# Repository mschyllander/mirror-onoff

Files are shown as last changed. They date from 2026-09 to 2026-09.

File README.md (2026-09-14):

<div align="center">

# MR MATZO / MIRROR CONTROLLER

### Turn on the mirror. Let the timer take care of the rest.

Automatic timer · Current sensing · Local web app · 3D-printed enclosure

[Hardware](docs/hardware.md) · [Measurements](docs/measurements.md) · [Enclosure](hardware/enclosure/) · [Gallery](docs/gallery.md)

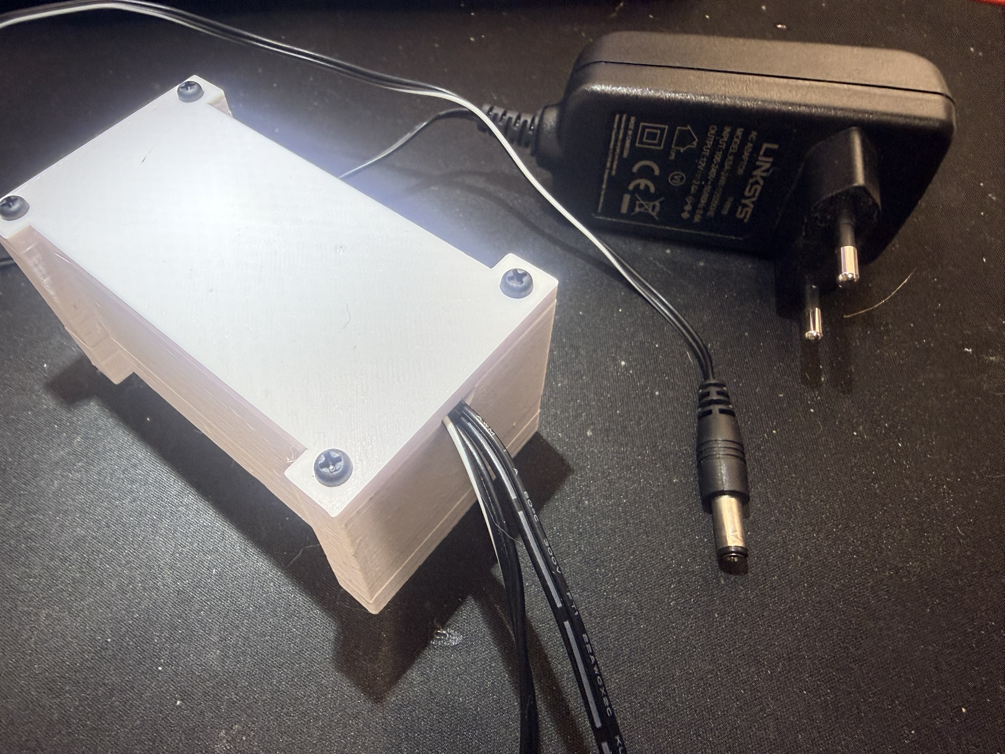
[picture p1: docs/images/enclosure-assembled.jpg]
Assembled mirror controller enclosure


**12 V mirror supply** &nbsp; / &nbsp; **INA219** &nbsp; / &nbsp; **ESP-12E**

</div>

## Why this exists

My wife never turns off her makeup mirror when she's finished. So I did what any reasonable person would do: built a Wi-Fi-enabled controller with current sensing, a web app and a custom 3D-printed enclosure to turn it off for her.

One forgotten light. One perfectly reasonable engineering project. ❤️

## The project

MrMatzo Mirror Controller is an ESP8266 timer app that switches a mirror's 12 V supply through a MOSFET. An INA219 measures current to detect when the mirror light is on and start an automatic timer. When the timer expires, the controller cuts power for three seconds to reset the mirror, then restores the 12 V supply.

The local web app at [mirror.local](http://mirror.local) displays current, voltage, power and remaining time. It also lets you set the timer duration and control the supply manually.

**Firmware 1.4.1 includes automatic shutdown recovery and password-protected browser OTA, with separate web and direct Wi-Fi passwords.** It has been compiled for NodeMCU 1.0 (ESP-12E) and checked with automated control-logic and upload-handler tests. Physical verification on the mirror is still required. The web interface and status messages are in Swedish. See [installation and OTA](firmware/README.md).

## How the timer works

1. The INA219 is read approximately every 100 ms. A moving average of ten samples smooths the current reading.
2. At least 31 mA for 700 ms confirms that the light is on and starts the timer when automatic mode is enabled and rearming is allowed.
3. The timer defaults to **10 minutes** and can be set to **1–1440 minutes**. The duration is saved in LittleFS.
4. When time runs out, 12 V is disconnected for **3 seconds**. Power is restored, followed by a **5-second** detection lockout.
5. A reading of at most 26 mA for 1000 ms confirms that the light is off. If it comes back on, the controller retries with **10-second**, then **30-second** interruptions.
6. If all three attempts fail, the controller **leaves 12 V off** and displays a fault. The fault persists across restart when LittleFS is available. Use the manual power-on button to acknowledge it. An unknown state after restoration also triggers bounded recovery.

Turning off the light before the timer expires stops the countdown. Between 26 and 31 mA, an already known light state is retained.

```mermaid
flowchart LR
    A[Light confirmed on] --> B[Timer counts down]
    B --> C[Cut 12 V for 3 s]
    C --> D[Restore 12 V]
    D --> E[Wait 5 s]
    E --> F{Light confirmed off?}
    F -->|Yes| A
    F -->|No| G[Retry with 10 s, then 30 s off]
    G --> H{Still not off?}
    H -->|Yes| I[Keep 12 V off until acknowledged]
    H -->|No| A
```

[Firmware and operation →](firmware/README.md)

## From prototype to enclosure

<table>
<tr>
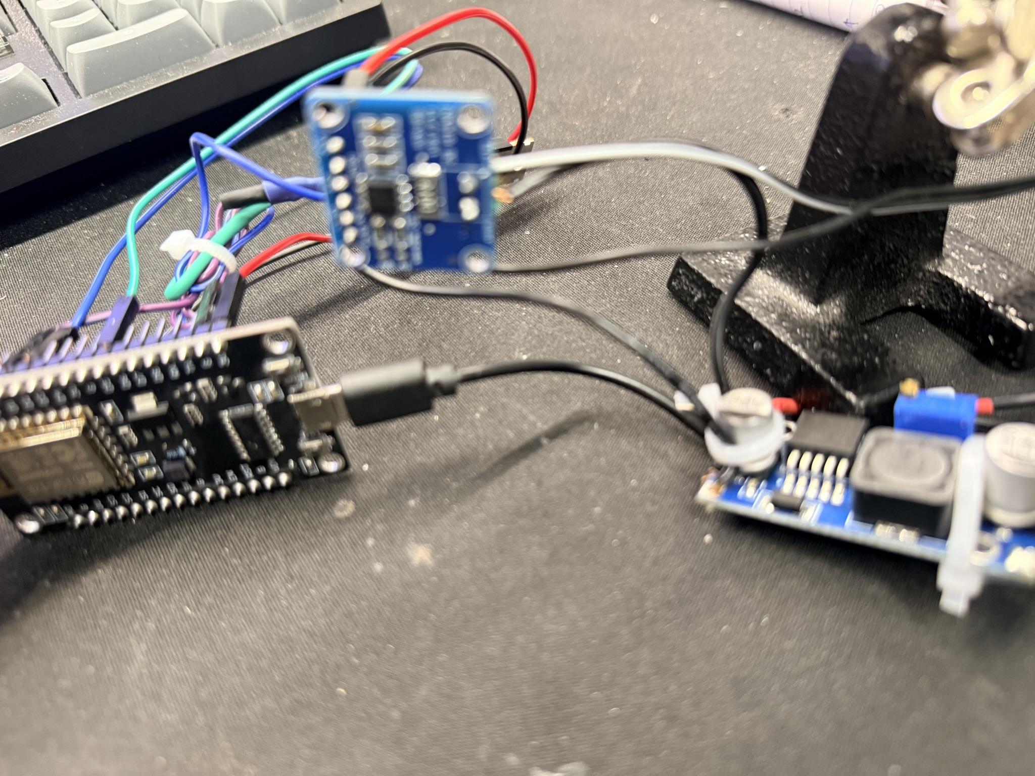
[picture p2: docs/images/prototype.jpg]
Electronics prototype on the workbench
<td width="50%"></td>
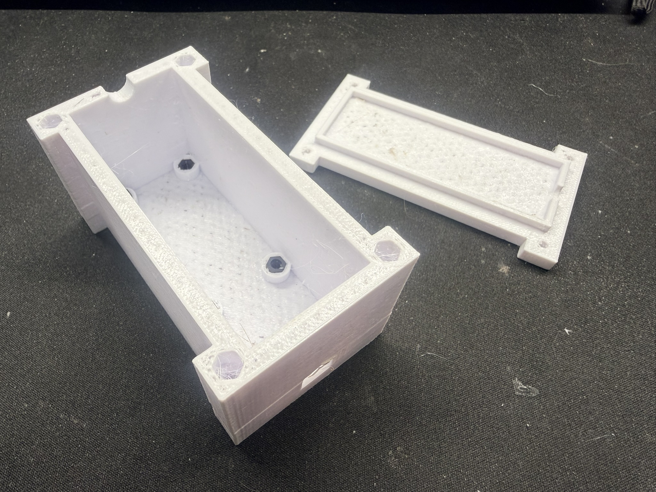
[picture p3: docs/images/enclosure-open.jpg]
3D-printed enclosure with separate lid
<td width="50%"></td>
</tr>
<tr><td><b>The electronics</b><br>Controller, current sensor and voltage converter.</td><td><b>The enclosure</b><br>Printed case with lid, screw mounts and cable openings.</td></tr>
</table>

## Current measurements

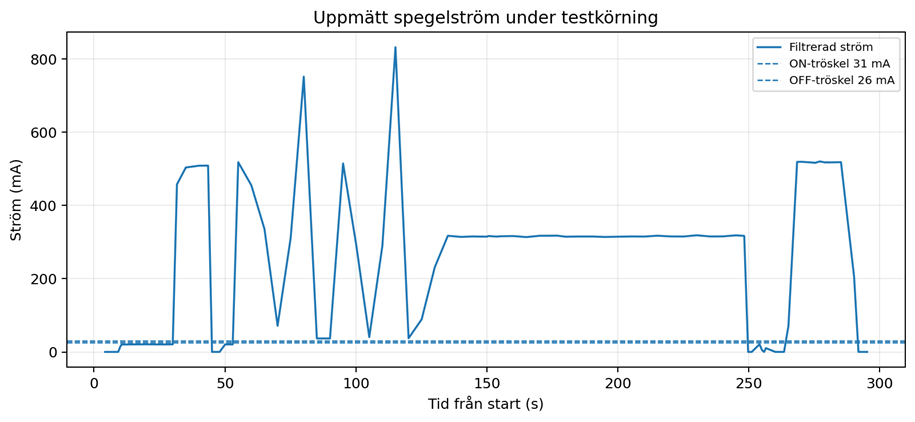
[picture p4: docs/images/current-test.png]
Measured mirror current during a test run


| Parameter | Value shown in the source material |
| :--- | :--- |
| ON threshold | 31 mA |
| OFF threshold | 26 mA |
| Threshold gap | 5 mA |
| Test duration | Approximately 295 seconds |

The plot shows steady current levels and brief peaks. The firmware uses hysteresis and confirmation periods to distinguish between on and off. The original plot has Swedish labels; an English label guide is included in the [measurement notes →](docs/measurements.md)

## Explore the repository

| Content | Location |
| :--- | :--- |
| Components and outstanding wiring details | [Hardware](docs/hardware.md) |
| Test plot and interpretation | [Measurements](docs/measurements.md) |
| All project photos | [Gallery](docs/gallery.md) |
| Enclosure model | [Box_mirror_onoff.3mf](hardware/enclosure/Box_mirror_onoff.3mf) |
| Firmware 1.3 and operation | [Firmware](firmware/README.md) |
| Remaining documentation | [Next steps](docs/next-steps.md) |

## Using the files

Open the 3MF file in compatible CAD or slicing software to inspect the enclosure. The model uses millimeters and contains two model objects. Check print settings and fit before printing; see the [enclosure documentation](hardware/enclosure/README.md).

The Arduino sketch, verified build configuration and OTA instructions are in [firmware](firmware/README.md). Firmware 1.3 needs one USB installation before wireless updates are available. A fully verified physical wiring diagram remains to be documented.

## License

Released under the [MIT License](LICENSE). Copyright © 2026 Mats Schyllander.

You are welcome to use and modify your own copy. Changes to this repository are
managed by the maintainer; see [Contributing](CONTRIBUTING.md).

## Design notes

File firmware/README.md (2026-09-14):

# Firmware · MrMatzo Mirror Controller 1.4.1

[Arduino sketch](esp_12V_mirror_timer/esp_12V_mirror_timer.ino) · [Release notes](../CHANGELOG.md)

## Install once by USB, then update over Wi-Fi

Version 1.3 has no OTA receiver. It must be replaced over USB once. Version 1.4.0 adds a browser upload page at `/update`; future updates can use that page.

1. Copy `DeviceConfig.example.h` to `DeviceConfig.h` in the sketch folder.
2. Set `MIRROR_ADMIN_PASSWORD` for the admin/update pages and `MIRROR_AP_PASSWORD` for direct Wi-Fi (8–63 ASCII characters). These are independent as of 1.4.1. The private header is ignored by Git; keep it for future builds.
3. Open `esp_12V_mirror_timer.ino` in Arduino IDE. Select **NodeMCU 1.0 (ESP-12E Module)** for the photographed board, and verify the actual board and flash capacity before uploading.
4. Compile and upload over USB using the settings below. Preserve the filesystem and Wi-Fi settings; do not erase all flash.
5. Open [mirror.local](http://mirror.local) on the same network, or use the device IP address. For a direct connection, join **Mirror-Setup** using your configured Wi-Fi password and open [192.168.4.1](http://192.168.4.1).
6. Select **UPPDATERA**, sign in as `admin` with your configured admin password, select the firmware `.bin` and install it. Keep the controller powered until it restarts, then check the firmware version at `/status`.

The spelling is `mirror.local`. Hostname resolution depends on the client/network; the IP address is the fallback. Direct Wi-Fi does not require a router or internet access. A phone may report that Mirror-Setup has no internet; stay connected to use the controller.

### Build verified for 1.4.0

| Component | Version / setting |
| :--- | :--- |
| ESP8266 Arduino core | 3.1.2 |
| Board FQBN | `esp8266:esp8266:nodemcuv2` |
| Flash layout | Board default: 4 MB flash, 2 MB filesystem |
| Adafruit INA219 | 1.2.3 |
| Adafruit BusIO | 1.17.4 |
| Serial monitor | 921600 baud |

The remaining libraries are supplied by the ESP8266 core: WiFi, WebServer, mDNS, Wire, LittleFS and Updater. WiFiManager is no longer required. The web app is embedded in the sketch.

```sh
arduino-cli compile --fqbn esp8266:esp8266:nodemcuv2 firmware/esp_12V_mirror_timer
```

Use the same flash layout as the installed firmware to retain logs/settings. The project device was read back on 2026-09-14: 4 MB flash with LittleFS from `0x200000` to `0x3FA000`, matching this profile. A binary built with your private header contains the password and should not be published as a generic release artifact.

## Automatic shutdown recovery

The previous firmware could cut power successfully, restore it to an illuminated mirror and then wait forever for OFF with no active timer. Version 1.4.0 retains the OFF confirmation requirement but adds a bounded recovery sequence:

| Attempt | Power off | After restoration |
| :--- | :--- | :--- |
| 1 | 3 seconds | Wait 5 seconds, then confirm light state |
| 2, if needed | 10 seconds | Wait 5 seconds, then confirm light state |
| 3, if needed | 30 seconds | Wait 5 seconds, then confirm light state |

A confirmed ON starts the next attempt immediately. If the state remains unknown for 15 seconds after restoration, the next attempt starts as well. After the third failure, 12 V remains off with **AVSTÄNGD EFTER SLÄCKFEL**. Manual power-on acknowledges the fault. If LittleFS is working, `/shutdown_fault.txt` preserves the fault across a controller restart; a filesystem failure prevents that persistence.

Confirmation of OFF clears the recovery sequence and allows the next normal timer. Manual OFF cancels any pending power restoration. Manual power cycling remains a single three-second interruption and clears the automatic rearm condition.

## Detection and timer settings

| Parameter | Value |
| :--- | :--- |
| Timer duration | 1–1440 minutes; default 10 minutes |
| Sensor interval | 100 ms, subject to main-loop scheduling |
| Filter | Moving average of 10 samples; negative raw readings clamped to 0 |
| Light on | Filtered current ≥ 31 mA for 700 ms |
| Light off | Filtered current ≤ 26 mA for 1000 ms |
| Between thresholds | Known state retained; unknown state remains unknown |
| Sensor calibration | `setCalibration_32V_2A()` |

Turning off the light stops an active timer. Changing the duration during a countdown starts a fresh countdown. Duration persists across restart; automatic mode and countdown progress do not. Automatic mode starts enabled. A latched shutdown fault keeps the supply off at boot; otherwise supply power is enabled.

If the sensor is missing at startup, the UI reports a sensor error and normal current detection is unavailable. This firmware does not provide an independent hardware cutoff or complete sensor-failure protection.

## Wi-Fi and update behavior

- The password-protected **Mirror-Setup** access point remains available alongside the existing home Wi-Fi connection.
- `/wifi` lets an authenticated administrator save new router credentials. Existing credentials from 1.3 are reused. Timer processing no longer waits for router connection or a blocking setup portal.
- OTA and Wi-Fi configuration use HTTP Digest authentication and a per-boot form token. Firmware uploads accept `.bin` files and write only the firmware area, not a filesystem image.
- An authorized firmware upload turns the mirror supply off and cancels pending automatic restoration. Failed or aborted uploads leave it off. A successful upload restarts the controller.
- Keep using the same private password header when building updates, unless intentionally changing a password. No device password is committed to this repository or returned by `/status`.
- Ordinary mirror controls remain unauthenticated on the local network, as in 1.3. HTTP is not encrypted; do not expose the controller through internet port forwarding. OTA images are not cryptographically signed.

## Logs and endpoints

Measurements are logged every ten seconds and at events. LittleFS retains `/mirror_log.csv` and one rotated `/mirror_log_old.csv`; rotation occurs when the current file reaches 200 KiB. The previous file is now available for download too. Rotation is finite retention, not a permanent archive.

CSV fields remain `session,uptime_ms,raw_mA,filtered_mA,bus_V,load_V,power_mW,state,event`. Time is uptime in milliseconds. `load_V` follows the original code's calculation of bus voltage plus shunt voltage.

| Path | Function |
| :--- | :--- |
| `/`, `/status` | Web app and JSON status |
| `/settime?minutes=10`, `/auto/toggle` | Duration and automatic mode |
| `/power/on`, `/power/off`, `/reset` | Manual supply control and power cycle |
| `/log`, `/log/download` | Current log |
| `/log/old/download` | Previous rotated log |
| `/log/clear` | Clear both log files |
| `/update` | Authenticated firmware upload |
| `/wifi` | Authenticated Wi-Fi configuration |
| `/wifi-reset` | Redirect to configuration; no longer erases credentials |

JSON status adds `shutdownFault`, `shutdownAttempt`, `otaInProgress` and `apIP`. New log events include `SHUTDOWN_RETRY_2`, `SHUTDOWN_RETRY_3`, `SHUTDOWN_CONFIRMED_OFF`, `SHUTDOWN_FAILED_LATCHED_OFF`, `OTA_STARTED`, `OTA_SUCCESS`, `OTA_FAILED`, `OTA_ABORTED` and `OTA_TIMEOUT`.

## Validation

```sh
python tests/test_controller.py
python tests/test_ota.py
```

These tests compile the actual sketch functions with C++ hardware stubs. They cover the observed 524 mA recovery failure, normal rearming, bounded retries, manual cancellation, unknown state, a missing sensor during recovery, threshold timing, millis rollover and filtering. Upload tests cover authentication, form tokens, missing/wrong files, flash errors, aborts and successful retry.

The firmware compiles for the profile above. On 2026-09-14, version 1.4.0 was installed over USB on the project device after a full flash backup. An authenticated OTA transfer of the same firmware completed successfully, followed by a verified reboot and `OTA_SUCCESS` in the log. The timer setting and filesystem were retained. Both the local hostname and LAN IP responded, the INA219 was detected, and unauthenticated access to `/update` returned HTTP 401. A separate direct Wi-Fi connection and physical mirror shutdown/retry test remain outstanding.

[Back to the project](../README.md)

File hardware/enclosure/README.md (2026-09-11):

# Enclosure

Printed enclosure and lid

[Download the 3MF model](Box_mirror_onoff.3mf)

The original file is included unchanged. The 3MF archive is readable and contains a model with two objects, millimeter units and an embedded preview. Printability and fit have not been verified.

## Embedded model preview

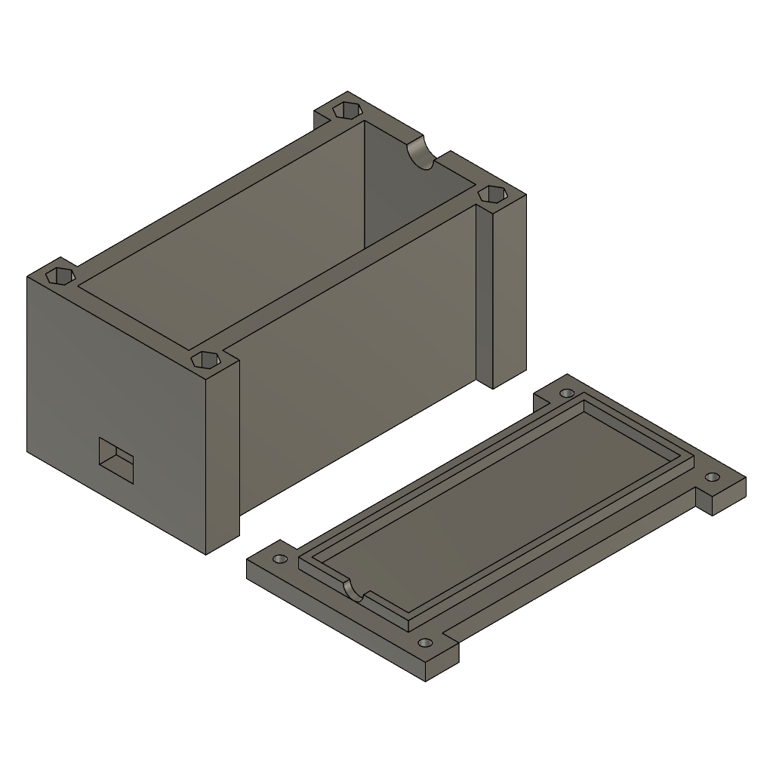
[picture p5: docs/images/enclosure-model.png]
Model preview embedded in the 3MF file


## Print details to document

| Detail | Status |
| :--- | :--- |
| Material | Not specified |
| Nozzle and layer height | Not specified |
| Walls and infill | Not specified |
| Orientation and supports | Not specified |
| Screws and nuts | Sizes not specified |
| Fit around the electronics | Not verified in this repository |

[Back to the project](../../README.md)

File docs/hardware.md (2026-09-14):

# Hardware

This overview is based on the project photos and firmware (GPIO assignments unchanged in 1.4.0). It is a component inventory, not a verified wiring diagram.

| Part | Identification from the photos | Still to document |
| :--- | :--- | :--- |
| Controller | ESP8266, module marked ESP-12E; board with D0–D8 and micro-USB | Exact board variant and power connection |
| Current sensor | INA219 DC Current Sensor, shunt marked R100 | Physical I²C address and wiring; code uses the default constructor and 32 V / 2 A calibration |
| Transistor | Separate component marked IRLB8721 | Confirm its installation and connections in the MOSFET switching circuit |
| DC/DC module | Adjustable module with a trimmer potentiometer | Exact model and configured input/output voltages |
| White power adapter | Royal BI24G-120200-AdV, output 12.0 V DC / 2.0 A / 24.0 W | Which adapter is used in the final build |
| Black power adapter | Linksys adapter visible beside the enclosure | Ratings and role in the project |
| Enclosure | Printed case with a separate screw-fastened lid | Material, screw sizes and mounting dimensions |

## GPIO assignments in the source

| Signal | Board pin | GPIO | Connection described in the source |
| :--- | :--- | :--- | :--- |
| MOSFET control | D1 | 5 | Gate through 100 Ω; gate to GND through 10 kΩ, according to the code comment |
| INA219 SDA | D2 | 4 | I²C data |
| INA219 SCL | D5 | 14 | I²C clock |

`setMirrorPower()` drives D1 HIGH for power on and LOW for power off. These pins are used in the implementation; the resistor values come from the introductory code comment. The physical wiring still needs to be checked against the build.

## Wiring

The photos do not establish the complete wiring. A reproducible build needs:

- The supply path through the mirror, sensor and controller.
- INA219 connections: VCC, GND, SDA, SCL, VIN+ and VIN−.
- IRLB8721 connections and any supporting components.
- The DC/DC module's configured output voltage and connection to the controller.
- Connector polarity and confirmation of the GPIO assignments above.

Do not infer connections solely from wire colors in the photos.

[Component photos](gallery.md) · [Back to the project](../README.md)

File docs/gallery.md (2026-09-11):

# Photo gallery

Original project images, copied without image processing.

## Assembled enclosure

Assembled enclosure

The case with its lid screwed on. A black Linksys power adapter sits beside it.

## Case and lid

Case and lid

The enclosure interior, mounts and cable openings.

## Prototype

Prototype

The electronics on the workbench during development.

## Controller board

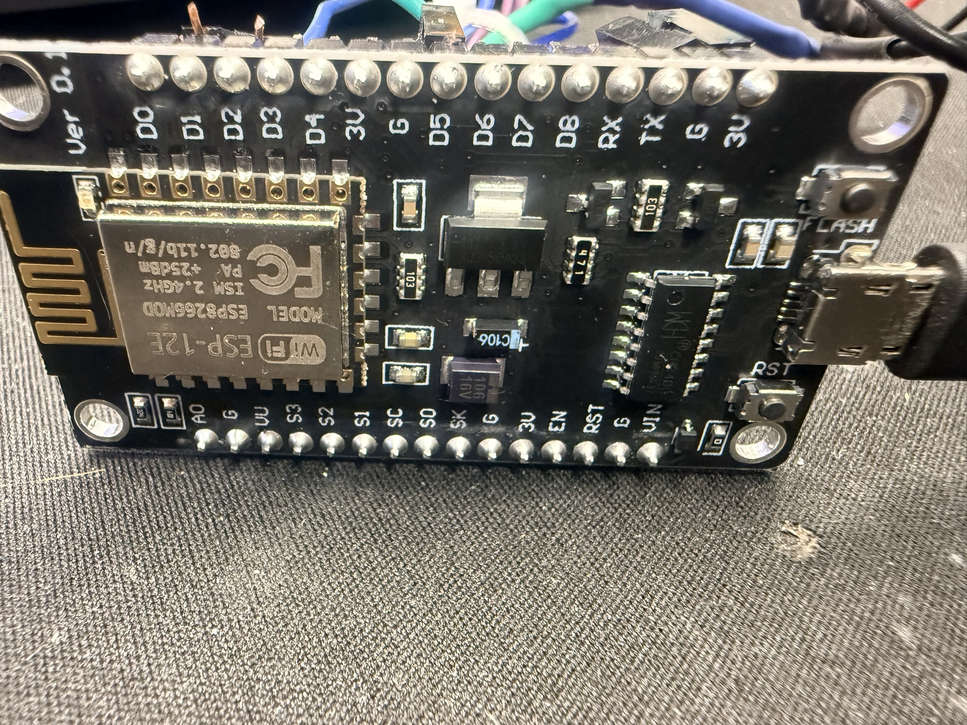
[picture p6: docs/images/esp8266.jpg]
Controller board


ESP8266 board with an ESP-12E module.

## Current sensor

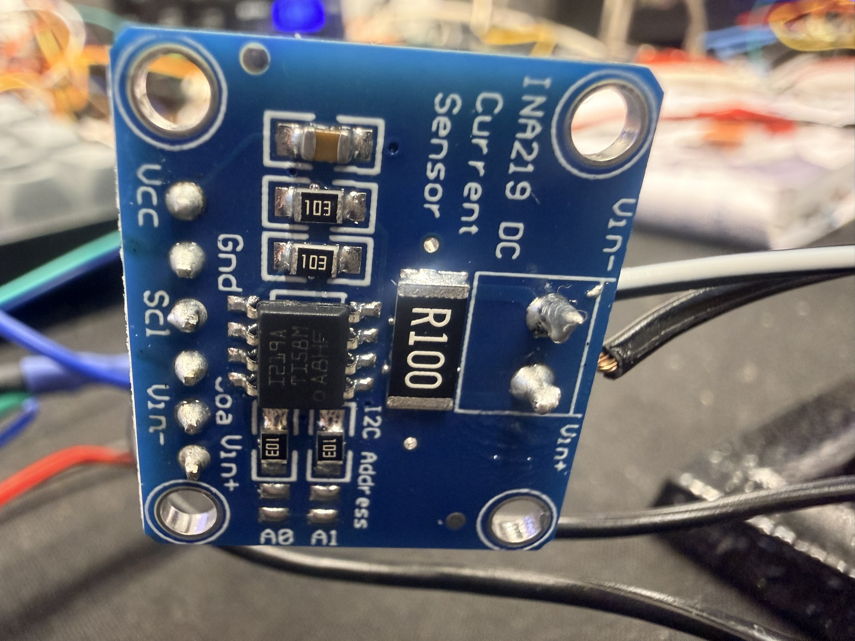
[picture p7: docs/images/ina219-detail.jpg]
Current sensor


A close-up of the INA219 module.

## Current sensor, alternate view

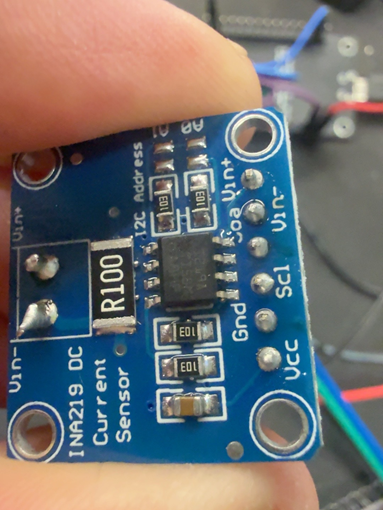
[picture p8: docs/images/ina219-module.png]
Current sensor, alternate view


Module markings and connections.

## DC/DC module

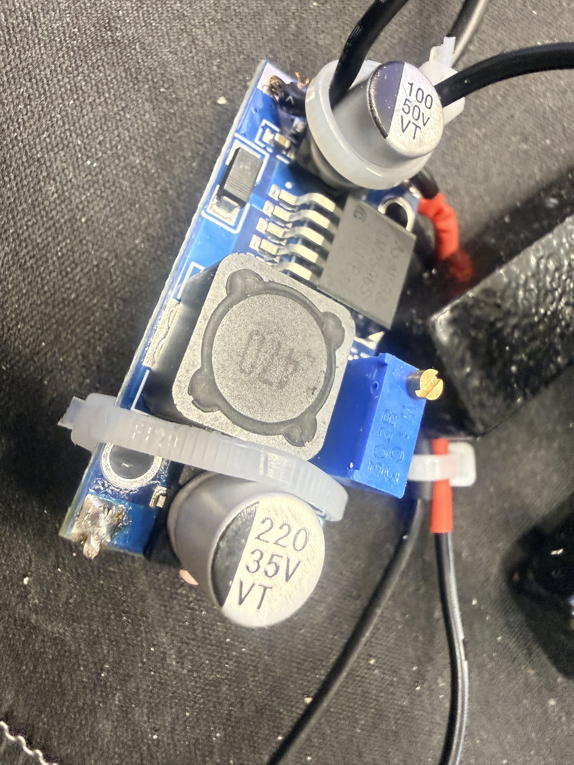
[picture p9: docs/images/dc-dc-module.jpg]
DC/DC module


Adjustable voltage converter.

## IRLB8721

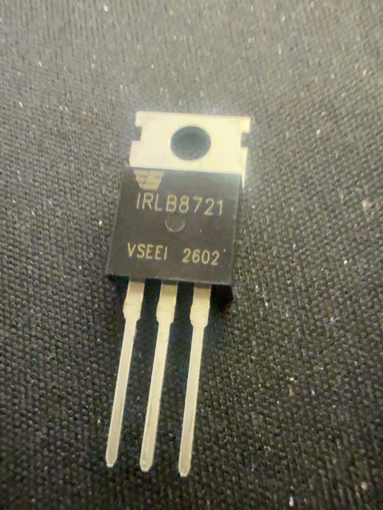
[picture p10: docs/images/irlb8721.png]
IRLB8721


The separate component, photographed before its installation was documented.

## White power adapter

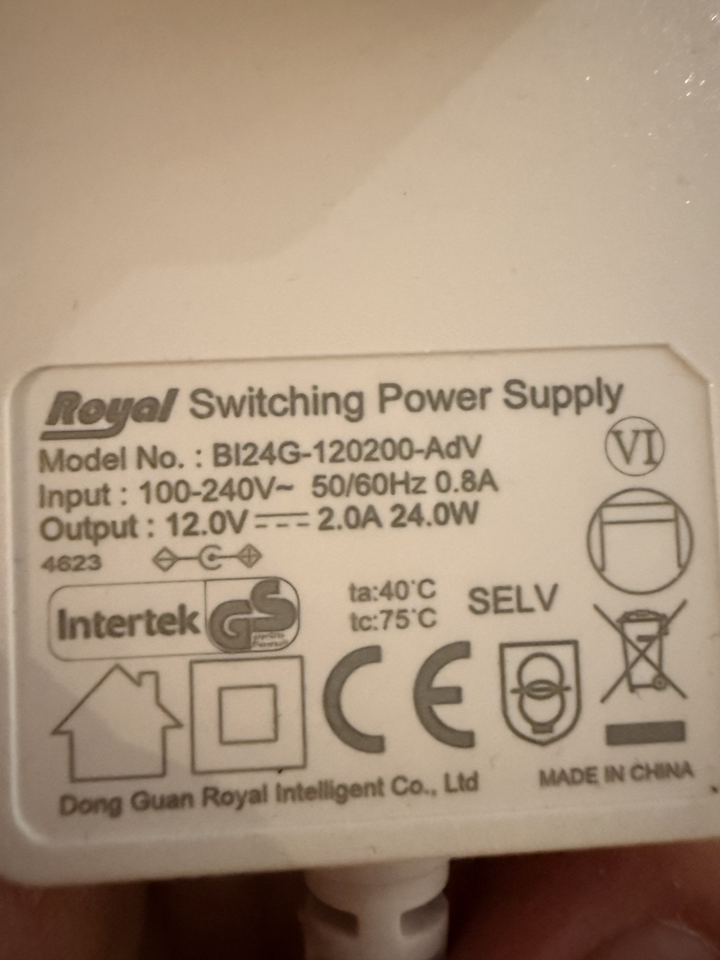
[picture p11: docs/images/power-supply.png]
White power adapter


Output rating: 12.0 V DC, 2.0 A and 24.0 W.

## Test run

Test run

Filtered current with marked thresholds. See the [measurement notes](measurements.md) for an English guide to the original Swedish labels.

[Back to the project](../README.md)

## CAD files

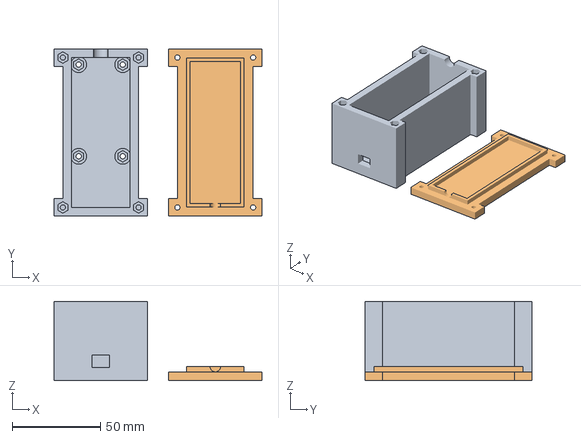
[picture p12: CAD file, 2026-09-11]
hardware/enclosure/Box_mirror_onoff.3mf
118.0 x 95.0 x 45.0 mm
Lada
Lock

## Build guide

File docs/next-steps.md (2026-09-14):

# Next steps

- [x] Collect project photos with descriptive filenames.
- [x] Include the original enclosure model.
- [x] Present the hardware and test plot.
- [x] Describe the mirror's behavior and the controller's purpose.
- [x] Include firmware 1.3 and document its operation.
- [x] Write the repository documentation in English.
- [x] Compile firmware 1.4.0 with documented NodeMCU / ESP8266 core / library versions.
- [x] Add and test bounded shutdown recovery and browser OTA.
- [x] Verify actual board flash layout, back up flash and install 1.4.0 over USB.
- [x] Verify authenticated OTA transfer, reboot, log event and preserved settings on the device.
- [ ] Verify shutdown recovery with the mirror connected and test a separate direct Wi-Fi connection.
- [ ] Document and verify the wiring diagram against the hardware; GPIO assignments are available from the source.
- [ ] Confirm which power adapter is used.
- [ ] Document print settings and mounting hardware.
- [ ] Add raw data and instructions for repeating the measurement.
- [x] Select the MIT license.
- [x] Publish on GitHub as `mschyllander/mirror-onoff` with public visibility.

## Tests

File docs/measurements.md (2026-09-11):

# Current measurements

Test run showing filtered current and ON/OFF thresholds

## Source material

The original plot is in Swedish. Its title translates to **Measured mirror current during a test run**. The horizontal axis shows seconds since startup; the vertical axis shows current in mA. The curve is labeled *Filtered current*.

| Original label | English |
| :--- | :--- |
| Tid från start (s) | Time since startup (s) |
| Ström (mA) | Current (mA) |
| Filtrerad ström | Filtered current |
| ON-tröskel 31 mA | ON threshold 31 mA |
| OFF-tröskel 26 mA | OFF threshold 26 mA |

No raw data file was supplied. Firmware 1.3 uses a moving average of ten current samples with a 100 ms read interval. It has not been established whether this exact version produced the plot.

## Reading the plot

| Observation | Approximate value |
| :--- | :--- |
| ON threshold stated in the legend | 31 mA |
| OFF threshold stated in the legend | 26 mA |
| Longer plateau, roughly 135–248 s | 315 mA |
| Higher plateaus | 500–520 mA |
| Highest visible peak | 830 mA |

Plateaus, times and the peak value are visual estimates from the image. Threshold values are explicitly stated in the legend.

## Firmware 1.3 logic

The thresholds are 5 mA apart. The code confirms ON when filtered current stays at or above 31 mA for 700 ms, and OFF at or below 26 mA for 1000 ms. Between thresholds, a known state is retained. Confirmed ON starts the timer when automatic mode is enabled and the rearming condition allows it.

The introductory code comment records approximately 20–21.5 mA with the mirror light off and 36–40 mA at its lowest on level. These are the project's recorded measurements, not new measurements made for this repository.

Reproducing the plot requires raw data, notes about events during the run and confirmation of the firmware version used.

[Firmware and complete timer behavior](../firmware/README.md) · [Back to the project](../README.md)

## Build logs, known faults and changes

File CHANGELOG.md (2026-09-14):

# Changelog

## 1.4.1 — 2026-09-14

- Separate the web admin password from the direct Wi-Fi password, allowing a shorter web password without changing the access point.
- Keep device-specific credentials in the private, gitignored configuration.

## 1.4.0 — 2026-09-14

- Fix the automatic shutdown deadlock when the mirror returns illuminated after a power cycle.
- Retry with 3, 10 and 30 second interruptions, then latch the supply off if shutdown cannot be confirmed.
- Preserve the shutdown fault across reboot in LittleFS; manual power-on acknowledges it.
- Add password-protected browser firmware updates at `/update` and a button in the existing Swedish UI.
- Add password-protected direct Wi-Fi access and `/wifi` configuration without blocking timer processing.
- Make the previous rotated log downloadable.
- Add regression tests for controller behavior and OTA upload handlers.

## 1.3

Original imported firmware: current-triggered timer, Swedish web interface, LittleFS logs and settings, and a single three-second power cycle. No OTA support.

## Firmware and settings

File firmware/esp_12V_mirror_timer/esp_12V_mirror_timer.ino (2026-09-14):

/*
   ============================================================
                 MR MATZO MIRROR CONTROLLER
                        Version 1.4.1
   ============================================================

   ESP8266 + INA219 + MOSFET + LittleFS + mDNS

   Web interface:
      http://mirror.local

   D1 / GPIO5  -> 100R -> MOSFET Gate
   Gate        -> 10k -> GND

   D2 / GPIO4  -> INA219 SDA
   D5 / GPIO14 -> INA219 SCL

   Current measurements from real mirror:

      OFF:       ~20.0 - 21.5 mA
      Lowest ON: ~36.0 - 40 mA
      High ON:   hundreds of mA

   Detection:

      OFF <= 26 mA
      ON  >= 31 mA

   Dead-band between 26 and 31 mA prevents chatter.
*/


// ============================================================
// LIBRARIES
// ============================================================

#include <ESP8266WiFi.h>
#include <ESP8266WebServer.h>
#include <ESP8266mDNS.h>
#include <Updater.h>
#include "ShutdownRecovery.h"
#include "DeviceConfig.h"
#include <Wire.h>
#include <Adafruit_INA219.h>
#include <LittleFS.h>


// ============================================================
// VERSION / NETWORK
// ============================================================

const char* FW_VERSION = "MrMatzo Mirror Controller 1.4.1";

const char* MDNS_HOSTNAME = "mirror";


// ============================================================
// HARDWARE
// ============================================================

const uint8_t MOSFET_PIN  = D1;
const uint8_t I2C_SDA_PIN = D2;
const uint8_t I2C_SCL_PIN = D5;

ESP8266WebServer server(80);
Adafruit_INA219 ina219;
ShutdownRecovery recovery;
bool otaInProgress = false;
bool otaSucceeded = false;
bool otaFailed = false;
bool otaAuthorized = false;
unsigned long otaLastActivity = 0;
bool fsOK = false;
bool mdnsStarted = false;
bool stationWasConnected = false;
String adminNonce;
const char* FAULT_FILE = "/shutdown_fault.txt";
const char* ADMIN_PASSWORD = MIRROR_ADMIN_PASSWORD;
static_assert(sizeof(MIRROR_ADMIN_PASSWORD) > 1, "Set an admin password");
static_assert(sizeof(MIRROR_AP_PASSWORD) >= 9 && sizeof(MIRROR_AP_PASSWORD) <= 64,
              "Choose an 8-63 character Wi-Fi password");


// ============================================================
// FILE SYSTEM
// ============================================================

const char* LOG_FILE      = "/mirror_log.csv";
const char* OLD_LOG_FILE  = "/mirror_log_old.csv";
const char* SETTINGS_FILE = "/settings.txt";
const char* SESSION_FILE  = "/session.txt";

const size_t MAX_LOG_SIZE = 200UL * 1024UL;


// ============================================================
// TIMER SETTINGS
// ============================================================

unsigned long timerIntervalMs =
  10UL * 60UL * 1000UL;

const unsigned long POWER_OFF_TIME_MS =
  3000UL;

const unsigned long SENSOR_LOCKOUT_MS =
  5000UL;


// ============================================================
// CURRENT DETECTION
// ============================================================

const float CURRENT_ON_THRESHOLD_MA =
  31.0;

const float CURRENT_OFF_THRESHOLD_MA =
  26.0;

const unsigned long ON_CONFIRM_MS =
  700UL;

const unsigned long OFF_CONFIRM_MS =
  1000UL;


// ============================================================
// SENSOR
// ============================================================

const unsigned long SENSOR_INTERVAL_MS =
  100UL;

const unsigned long LOG_INTERVAL_MS =
  10000UL;

unsigned long lastSensorRead = 0;
unsigned long lastLogWrite   = 0;

float rawCurrent_mA      = 0.0;
float filteredCurrent_mA = 0.0;

float busVoltage_V       = 0.0;
float loadVoltage_V      = 0.0;
float shuntVoltage_mV    = 0.0;
float power_mW           = 0.0;


// ============================================================
// CURRENT FILTER
// ============================================================

const uint8_t FILTER_SIZE = 10;

float currentBuffer[FILTER_SIZE];

uint8_t filterIndex = 0;
uint8_t filterCount = 0;


// ============================================================
// SYSTEM STATE
// ============================================================

bool inaOK       = false;
bool powerOn     = true;
bool autoEnabled = true;

bool timerActive     = false;
bool resetInProgress = false;
bool sensorLockout   = true;

bool mirrorStateValid = false;
bool mirrorIsOn       = false;

bool requireOffBeforeRearm = false;

bool onCandidate  = false;
bool offCandidate = false;

unsigned long onCandidateStarted  = 0;
unsigned long offCandidateStarted = 0;

unsigned long timerStarted   = 0;
unsigned long resetStarted   = 0;
unsigned long lockoutStarted = 0;

uint32_t sessionNumber = 0;


// ============================================================
// JSON ESCAPE
// ============================================================

String jsonEscape(String s)
{
  s.replace("\\", "\\\\");
  s.replace("\"", "\\\"");
  s.replace("\r", "");
  s.replace("\n", "\\n");

  return s;
}


// ============================================================
// USER-FACING STATE
// ============================================================

String getStateText()
{
  if (otaInProgress) return "UPPDATERAR PROGRAMVARAN";
  if (recovery.fault) return "AVSTÄNGD EFTER SLÄCKFEL";
  if (!inaOK)
    return "SENSORFEL";

  if (resetInProgress)
    return "STARTAR OM SPEGELN";

  if (!powerOn)
    return "SPEGELSTRÖM AV";

  if (sensorLockout)
    return "KONTROLLERAR SPEGELN";

  if (!mirrorStateValid)
    return "LÄSER AV SPEGELN";

  if (mirrorIsOn)
  {
    if (timerActive)
      return "SPEGEL TÄND";

    if (!autoEnabled)
      return "SPEGEL TÄND";

    if (requireOffBeforeRearm)
      return "KONTROLLERAR SLÄCKNING";

    return "SPEGEL TÄND";
  }

  return "SPEGEL SLÄCKT";
}


String getDescriptionText()
{
  if (otaInProgress) return "Matningen är av under uppdateringen. Bryt inte strömmen till styrenheten.";
  if (recovery.fault) return "Spegeln slocknade inte efter tre försök. 12 V är av. Tryck SPEGELSTRÖM PÅ för att försöka igen.";
  if (!inaOK)
    return "Strömsensorn INA219 kunde inte hittas.";

  if (resetInProgress)
    return "Strömmen är tillfälligt bruten för att återställa spegeln.";

  if (!powerOn)
    return "12 V till spegeln är manuellt frånkopplad.";

  if (sensorLockout)
    return "Systemet väntar några sekunder och läser sedan spegelns ström.";

  if (!mirrorStateValid)
    return "Bestämmer om spegelbelysningen är tänd eller släckt.";

  if (mirrorIsOn)
  {
    if (timerActive)
      return "Automatisk avstängning är aktiv.";

    if (!autoEnabled)
      return "Ljuset är tänt. Automatisk avstängning är avstängd.";

    if (requireOffBeforeRearm)
      return "Kontrollerar släckningen. Vid behov görs ett längre släckförsök.";

    return "Ljuset är tänt.";
  }

  if (autoEnabled)
    return "Timern startar automatiskt nästa gång du tänder spegeln.";

  return "Spegeln är släckt. Automatisk avstängning är avstängd.";
}


// ============================================================
// LOG FILE
// ============================================================

void createLogHeader()
{
  File f =
    LittleFS.open(
      LOG_FILE,
      "w"
    );

  if (!f)
    return;

  f.println(
    "session,uptime_ms,raw_mA,filtered_mA,"
    "bus_V,load_V,power_mW,state,event"
  );

  f.close();
}


void rotateLogIfNeeded()
{
  if (!LittleFS.exists(LOG_FILE))
    return;

  File f =
    LittleFS.open(
      LOG_FILE,
      "r"
    );

  if (!f)
    return;

  size_t fileSize =
    f.size();

  f.close();

  if (fileSize < MAX_LOG_SIZE)
    return;

  if (LittleFS.exists(OLD_LOG_FILE))
    LittleFS.remove(OLD_LOG_FILE);

  LittleFS.rename(
    LOG_FILE,
    OLD_LOG_FILE
  );

  createLogHeader();
}


void writeLog(const String& event)
{
  if (!fsOK || otaInProgress) return;
  rotateLogIfNeeded();

  File f =
    LittleFS.open(
      LOG_FILE,
      "a"
    );

  if (!f)
    return;

  f.print(sessionNumber);
  f.print(",");

  f.print(millis());
  f.print(",");

  f.print(rawCurrent_mA, 2);
  f.print(",");

  f.print(filteredCurrent_mA, 2);
  f.print(",");

  f.print(busVoltage_V, 3);
  f.print(",");

  f.print(loadVoltage_V, 3);
  f.print(",");

  f.print(power_mW, 1);
  f.print(",");

  f.print(getStateText());
  f.print(",");

  f.println(event);

  f.close();
}


void logEvent(const String& text)
{
  Serial.print("[EVENT] ");
  Serial.println(text);

  writeLog(text);
}


// ============================================================
// SESSION
// ============================================================

void loadSession()
{
  sessionNumber = 0;

  if (LittleFS.exists(SESSION_FILE))
  {
    File f =
      LittleFS.open(
        SESSION_FILE,
        "r"
      );

    if (f)
    {
      sessionNumber =
        f.readString().toInt();

      f.close();
    }
  }

  sessionNumber++;

  File f =
    LittleFS.open(
      SESSION_FILE,
      "w"
    );

  if (f)
  {
    f.print(sessionNumber);
    f.close();
  }
}


// ============================================================
// SETTINGS
// ============================================================

void saveSettings()
{
  File f =
    LittleFS.open(
      SETTINGS_FILE,
      "w"
    );

  if (!f)
    return;

  f.print(
    timerIntervalMs /
    60000UL
  );

  f.close();
}


void loadSettings()
{
  if (!LittleFS.exists(SETTINGS_FILE))
    return;

  File f =
    LittleFS.open(
      SETTINGS_FILE,
      "r"
    );

  if (!f)
    return;

  String line =
    f.readString();

  f.close();

  long minutes =
    line.toInt();

  if (
    minutes >= 1 &&
    minutes <= 1440
  )
  {
    timerIntervalMs =
      (unsigned long)minutes *
      60000UL;
  }
}


// ============================================================
// MOSFET
// ============================================================

void setMirrorPower(bool on)
{
  powerOn = on;

  digitalWrite(
    MOSFET_PIN,
    on ? HIGH : LOW
  );

  Serial.print("Mirror 12V: ");

  Serial.println(
    on ? "ON" : "OFF"
  );
}


// ============================================================
// CURRENT FILTER
// ============================================================

void clearCurrentFilter()
{
  for (
    uint8_t i = 0;
    i < FILTER_SIZE;
    i++
  )
  {
    currentBuffer[i] = 0;
  }

  filterIndex = 0;
  filterCount = 0;

  rawCurrent_mA      = 0;
  filteredCurrent_mA = 0;
}


void addCurrentSample(float value)
{
  currentBuffer[filterIndex] =
    value;

  filterIndex++;

  if (filterIndex >= FILTER_SIZE)
    filterIndex = 0;

  if (filterCount < FILTER_SIZE)
    filterCount++;

  float total = 0;

  for (
    uint8_t i = 0;
    i < filterCount;
    i++
  )
  {
    total += currentBuffer[i];
  }

  if (filterCount > 0)
  {
    filteredCurrent_mA =
      total /
      filterCount;
  }
}


// ============================================================
// INA219
// ============================================================

void readINA219()
{
  if (!inaOK)
    return;

  if (
    millis() -
    lastSensorRead <
    SENSOR_INTERVAL_MS
  )
  {
    return;
  }

  lastSensorRead =
    millis();

  shuntVoltage_mV =
    ina219.getShuntVoltage_mV();

  busVoltage_V =
    ina219.getBusVoltage_V();

  rawCurrent_mA =
    ina219.getCurrent_mA();

  power_mW =
    ina219.getPower_mW();

  loadVoltage_V =
    busVoltage_V +
    (
      shuntVoltage_mV /
      1000.0
    );

  if (rawCurrent_mA < 0)
    rawCurrent_mA = 0;

  addCurrentSample(
    rawCurrent_mA
  );
}


// ============================================================
// TIMER
// ============================================================

void startTimer()
{
  if (!autoEnabled)
    return;

  if (!mirrorIsOn)
    return;

  if (requireOffBeforeRearm)
    return;

  timerActive =
    true;

  timerStarted =
    millis();

  logEvent(
    "TIMER_STARTED"
  );
}


void stopTimer(
  const String& reason
)
{
  if (!timerActive)
    return;

  timerActive =
    false;

  logEvent(
    "TIMER_STOPPED_" +
    reason
  );
}


unsigned long getRemainingMs()
{
  if (!timerActive)
    return 0;

  unsigned long elapsed =
    millis() -
    timerStarted;

  if (elapsed >= timerIntervalMs)
    return 0;

  return
    timerIntervalMs -
    elapsed;
}


void beginPowerCycle()
{
  recovery.beginAttempt();
  timerActive =
    false;

  resetInProgress =
    true;

  resetStarted =
    millis();

  requireOffBeforeRearm =
    true;

  mirrorStateValid =
    false;

  mirrorIsOn =
    false;

  onCandidate =
    false;

  offCandidate =
    false;

  setMirrorPower(
    false
  );

  logEvent(
    recovery.attempts == 1 ? "TIMER_EXPIRED_POWER_OFF" :
    "SHUTDOWN_RETRY_" + String(recovery.attempts)
  );
}


void processTimer()
{
  if (!timerActive)
    return;

  if (
    millis() -
    timerStarted >=
    timerIntervalMs
  )
  {
    beginPowerCycle();
  }
}


// ============================================================
// POWER CYCLE
// ============================================================

void processPowerCycle()
{
  if (otaInProgress || recovery.fault) return;
  if (!resetInProgress)
    return;

  if (
    millis() -
    resetStarted <
    (recovery.pending ? recovery.offTimeMs() : POWER_OFF_TIME_MS)
  )
  {
    return;
  }

  resetInProgress =
    false;

  setMirrorPower(
    true
  );

  clearCurrentFilter();

  sensorLockout =
    true;

  lockoutStarted =
    millis();

  mirrorStateValid =
    false;

  mirrorIsOn =
    false;

  onCandidate =
    false;

  offCandidate =
    false;

  recovery.restored(millis());

  logEvent(
    "POWER_RESTORED"
  );
}


// ============================================================
// SENSOR LOCKOUT
// ============================================================

void processSensorLockout()
{
  if (!sensorLockout)
    return;

  if (
    millis() -
    lockoutStarted <
    SENSOR_LOCKOUT_MS
  )
  {
    return;
  }

  sensorLockout =
    false;

  mirrorStateValid =
    false;

  onCandidate =
    false;

  offCandidate =
    false;

  logEvent(
    "SENSOR_READY"
  );
}


// ============================================================
// MIRROR STATE
// ============================================================

void confirmedMirrorOff()
{
  if (recovery.pending) logEvent("SHUTDOWN_CONFIRMED_OFF");
  recovery.clear();
  bool wasOn =
    mirrorStateValid &&
    mirrorIsOn;

  mirrorStateValid =
    true;

  mirrorIsOn =
    false;

  onCandidate =
    false;

  offCandidate =
    false;

  requireOffBeforeRearm =
    false;

  if (timerActive)
  {
    stopTimer(
      "MIRROR_OFF"
    );
  }

  if (wasOn)
  {
    logEvent(
      "MIRROR_LIGHT_OFF"
    );
  }
  else
  {
    logEvent(
      "MIRROR_CONFIRMED_OFF"
    );
  }
}


void confirmedMirrorOn()
{
  bool wasOff =
    !mirrorStateValid ||
    !mirrorIsOn;

  mirrorStateValid =
    true;

  mirrorIsOn =
    true;

  onCandidate =
    false;

  offCandidate =
    false;

  if (wasOff)
  {
    logEvent(
      "MIRROR_LIGHT_ON"
    );
  }

  if (
    autoEnabled &&
    !timerActive &&
    !requireOffBeforeRearm
  )
  {
    startTimer();
  }
}


// ============================================================
// MIRROR DETECTION
// ============================================================

void processMirrorDetection()
{
  if (!inaOK)
    return;

  if (!powerOn)
    return;

  if (resetInProgress)
    return;

  if (sensorLockout)
    return;


  // ----------------------------------------------------------
  // UNKNOWN STATE
  // ----------------------------------------------------------

  if (!mirrorStateValid)
  {
    if (
      filteredCurrent_mA <=
      CURRENT_OFF_THRESHOLD_MA
    )
    {
      onCandidate =
        false;

      if (!offCandidate)
      {
        offCandidate =
          true;

        offCandidateStarted =
          millis();
      }

      if (
        millis() -
        offCandidateStarted >=
        OFF_CONFIRM_MS
      )
      {
        confirmedMirrorOff();
      }
    }

    else if (
      filteredCurrent_mA >=
      CURRENT_ON_THRESHOLD_MA
    )
    {
      offCandidate =
        false;

      if (!onCandidate)
      {
        onCandidate =
          true;

        onCandidateStarted =
          millis();
      }

      if (
        millis() -
        onCandidateStarted >=
        ON_CONFIRM_MS
      )
      {
        confirmedMirrorOn();
      }
    }

    else
    {
      onCandidate =
        false;

      offCandidate =
        false;
    }

    return;
  }


  // ----------------------------------------------------------
  // MIRROR CURRENTLY ON
  // ----------------------------------------------------------

  if (mirrorIsOn)
  {
    if (
      filteredCurrent_mA <=
      CURRENT_OFF_THRESHOLD_MA
    )
    {
      if (!offCandidate)
      {
        offCandidate =
          true;

        offCandidateStarted =
          millis();
      }

      if (
        millis() -
        offCandidateStarted >=
        OFF_CONFIRM_MS
      )
      {
        confirmedMirrorOff();
      }
    }
    else
    {
      offCandidate =
        false;
    }

    return;
  }


  // ----------------------------------------------------------
  // MIRROR CURRENTLY OFF
  // ----------------------------------------------------------

  if (
    filteredCurrent_mA >=
    CURRENT_ON_THRESHOLD_MA
  )
  {
    if (!onCandidate)
    {
      onCandidate =
        true;

      onCandidateStarted =
        millis();
    }

    if (
      millis() -
      onCandidateStarted >=
      ON_CONFIRM_MS
    )
    {
      confirmedMirrorOn();
    }
  }
  else
  {
    onCandidate =
      false;
  }
}


// ============================================================
// PERIODIC LOGGING
// ============================================================

void processLogging()
{
  if (
    millis() -
    lastLogWrite <
    LOG_INTERVAL_MS
  )
  {
    return;
  }

  lastLogWrite =
    millis();

  writeLog("-");
}


// ============================================================
// WEB PAGE
// ============================================================

const char MAIN_PAGE[] PROGMEM = R"rawliteral(
<!DOCTYPE html>
<html lang="sv">

<head>

<meta charset="UTF-8">

<meta
  name="viewport"
  content="width=device-width,initial-scale=1,user-scalable=no">

<meta
  name="theme-color"
  content="#090b10">

<title>MrMatzo Mirror</title>

<style>

:root
{
  --bg:#090b10;
  --panel:#111620;
  --panel2:#171d28;
  --line:rgba(255,255,255,.07);

  --text:#f4f4f5;
  --muted:#7f8998;

  --gold:#f5bb42;
  --gold2:#d98c20;

  --green:#46d693;
  --red:#ff6273;
  --blue:#57a8ff;
}

*
{
  box-sizing:border-box;
}

body
{
  margin:0;

  background:
    radial-gradient(
      circle at 50% -120px,
      #313b52 0,
      #11151e 35%,
      #080a0e 75%
    );

  min-height:100vh;

  color:var(--text);

  font-family:
    -apple-system,
    BlinkMacSystemFont,
    "Segoe UI",
    sans-serif;

  padding:8px;
}

.app
{
  max-width:430px;
  margin:0 auto;
}

header
{
  display:flex;
  justify-content:space-between;
  align-items:center;

  margin:2px 4px 7px;
}

.brand
{
  font-size:19px;
  font-weight:900;
  letter-spacing:2.5px;
}

.brandSmall
{
  margin-top:1px;

  color:var(--muted);

  font-size:8px;
  letter-spacing:2.4px;
}

.connection
{
  text-align:right;

  font-size:9px;

  color:var(--green);

  font-weight:700;

  letter-spacing:.6px;
}

.card
{
  border:1px solid var(--line);

  background:
    linear-gradient(
      145deg,
      rgba(24,30,42,.97),
      rgba(13,17,24,.98)
    );

  border-radius:15px;

  box-shadow:
    0 12px 28px rgba(0,0,0,.28);

  padding:10px;

  margin-bottom:7px;
}


/* ==========================================================
   MAIN STATUS
   ========================================================== */

.main
{
  display:grid;

  grid-template-columns:156px 1fr;

  gap:10px;

  align-items:center;
}

.dial
{
  position:relative;

  width:150px;
  height:150px;

  margin:auto;
}

.dial svg
{
  width:150px;
  height:150px;

  transform:rotate(-90deg);
}

.ringBackground
{
  fill:none;

  stroke:#29303b;

  stroke-width:9;
}

.ring
{
  fill:none;

  stroke:url(#goldGradient);

  stroke-width:9;

  stroke-linecap:round;

  stroke-dasharray:402.12;
  stroke-dashoffset:402.12;

  filter:
    drop-shadow(
      0 0 5px
      rgba(245,187,66,.55)
    );
}

.dialCenter
{
  position:absolute;

  inset:0;

  display:flex;

  flex-direction:column;

  align-items:center;
  justify-content:center;

  text-align:center;
}

.countdown
{
  font-size:29px;

  font-weight:350;

  font-variant-numeric:
    tabular-nums;

  letter-spacing:-1px;
}

.countdown.ready
{
  font-size:21px;

  font-weight:800;

  letter-spacing:.4px;
}
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
void loop()
{
  // Web server
  server.handleClient();
  bool stationConnected = WiFi.status() == WL_CONNECTED;
  if (stationConnected != stationWasConnected) {
    stationWasConnected = stationConnected;
    setupMDNS();
  }


  // mDNS
  MDNS.update();


  if (otaInProgress) {
    if (millis() - otaLastActivity > 30000UL) {
      if (Update.isRunning()) Update.end();
      otaInProgress = false;
      otaFailed = true;
      logEvent("OTA_TIMEOUT");
    }
    yield();
    return;
  }

  // INA219
  readINA219();


  // Manual power cycle or bounded automatic shutdown attempt.
  processPowerCycle();


  // Sensor startup delay
  processSensorLockout();


  // Detect physical mirror light
  processMirrorDetection();


  // Never strand the controller in requireOffBeforeRearm.
  processShutdownRecovery();

  // Automatic shutdown timer
  processTimer();


  // Diagnostic log
  processLogging();


  // ----------------------------------------------------------
  // WIFI RECONNECT
  // ----------------------------------------------------------

  static unsigned long
    lastWiFiCheck = 0;


  if (
    millis() -
    lastWiFiCheck >=
    10000UL
  )
  {
    lastWiFiCheck =
      millis();


    if (
      WiFi.status() !=
      WL_CONNECTED
    )
    {
      WiFi.reconnect();
    }
  }


  yield();
}

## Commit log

2026-09-11 Add mirror project presentation, hardware photos and enclosure model
    [Box_mirror_onoff.3mf]
2026-09-11 Add original timer firmware and document current-triggered mirror control
2026-09-14 Fix shutdown recovery and add authenticated browser OTA
    [esp_12V_mirror_timer.ino]
2026-09-14 Record successful USB installation and device OTA verification
